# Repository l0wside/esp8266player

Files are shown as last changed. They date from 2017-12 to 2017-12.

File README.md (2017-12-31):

esp8266player - Kindgerechte Steuerung für einen Raumfeld One S
===============================================================

Motivation
----------
Der Player ist inspiriert von der [Toniebox](https://tonies.de/). Wer´s nicht kennt: das Kind hat ein Gerät, darauf stellt es eine Figur (die eine RFID-Kennung enthält), das Gerät lädt sich vom Server die zughörige Audiodatei und spielt los. Kein Gefummel mit CDs, die sowieso immer zerkratzen.

Nachteile an diesem System: man ist auf die Firma angewiesen, ohne Tonies keine Toniebox. Ohne Login geht nichts. Und: alle vorhandenen CDs (und bei uns sind das eine Menge) taugen nur noch als Frisbee oder Briefbeschwerer, eigene Inhalte lassen sich nur schwer wiedergeben.

Umsetzung
---------
Mit der Soft- und Hardware in diesem Projekt lässt sich ein Raumfeld One S per RFID fernsteuern. Dazu wird die sog. URI, die einen Track eindeutig bezeichnet, auf der Mifare-Karte gespeichert. Wird diese Karte dann auf den Player gelegt, sendet diese die URI an den Raumfeld One S, der diese URi dann abspielt. 
Vorteil: alles, was man mit der Raumfeld-App abspielen kann, lässt sich auch auf der Karte speichern. Theoretisch jedenfalls, ich habe es nur mit gerippten CDs auf dem NAS getestet.

Die Bedienung ist maximal simpel: Karte auflegen, ein paar Sekunden warten, Raumfeld dudelt los.

Programmiert werden die Karten ganz einfach: mit der Raumfeld-App einen Track auswählen. Wenn er spielt, auf den Player eine leere Mifare 1k-Karte legen. Der Player erkennt diese und schreibt die URI des aktuellen Tracks darauf. 

Wird die Karte nun wieder aufgelegt, wird der Track als neue URI an den Raumfeld gesendet, und dieser beginnt zu spielen. Wird die Karte weggenommen, wird ein Stop-Befehl an den Raumfeld gesendet.
Alle 20s wird die aktuelle Tracknummer abgefragt und (bei Änderung) auf der Karte gespeichert, so dass, wenn die Karte erneut aufgelegt wird, die CD nicht wieder von vorne losläuft. Was passiert, wenn ein Radiosender oder Spotify eingestellt ist, ist nicht getestet.

Bei uns sind statt RFID-Karten Aufkleber im Einsatz, die auf Holzwürfel geklebt werden. Irgendwann beschrifte ich die noch mit dem Laser.

Sonos und Co
------------
Implementiert ist ganz normales UPnP, das vermutlich mit einer Änderung des initialen Ports (bei Raumfeld 47365) auch mit Sonos läuft. Mangels Sonos habe ich es aber nicht getestet, ich freue mich auf Pull Requests.

Software
--------
Ein erster Umsetzungsversuch mit MicroPython scheiterte am komplett unbenutzbaren Netwerkstack von uPy auf ESP8266. Jetzt basiert die Software auf Arduino. Für RFID nutze ich die Lib von Miguel Balboa, der Zugriff auf den Raumfeld (SOAP über HTTP) ist selbst implementiert.

Hardware
--------
Basis ist ein ESP8266 (ESP13) auf dem im Repository enthaltenen Board. Achtung: der Schaltregler auf dem Board funktioniert zwar prinzipiell, bräuchte aber eine Spule, die größer ist, als der Platz erlaubt. Eine Vorgängerversion hatte mal einen LP3874-3.3 (Linearregler) eingebaut, der funktionierte erheblich besser.
Für Lauter, Leiser, Vor, Zurück sind insgesamt vier Touchfelder vorhanden, die mit Azoteq IQS127D ausgewertet werden. Wer sich das nicht traut, kann auch normale Taster nehmen, muss aber dafür sorgen, dass die Bootkonfiguration weiterhin funktioniert.
Für RFID kommt ein Chinaboard mit RC522 zum Einsatz, wie sie für rund 5 EUR z.B. bei eBay zu bekommen sind.

To Do
-----
* Hardware
  * Nicht funktionierenden Schaltregler sanieren oder durch Linearregler ersetzen
  * Einspeisung über Micro-USB-Buchse statt fest verlöteten Anschluss
  * Die Pinreihenfolge beim Anschluss des RFID-Boards müsste umgedreht werden, dann lässt sich 1:1 verbinden
  * Alternativ: RC522 direkt auf dem Board bestücken und Antenne integrieren.
* Software
  * Ist der Raumfeld im Standby, wird er nicht geweckt. 
  * Gelegentlich funktioniert die Erkennung der RFID-Karten nach einer Weile nicht mehr.
  * Als Status-LED wäre eine WS2812 prima, die dann farblich anzeigen könnte, wie es dem Gerät geht (suche WLAN, suche Raumfeld, Raumfeld gefunden, Karte im Feld, Raumfeld spielt). Das aktuelle Geblinke der blauen LED ist eher nervig.
  * Lauter/Leiser funktioniert nur mittelprächtig (in der App ist das viel besser). Wahrscheinlich wäre es sinnvoll, dafür eine permanent offene HTTP-Verbindung zu halten (also nicht Connection: close, sondern Connection: keep-alive) und mit inkrementellen statt absoluten Lautstärkebefehlen zu arbeiten.

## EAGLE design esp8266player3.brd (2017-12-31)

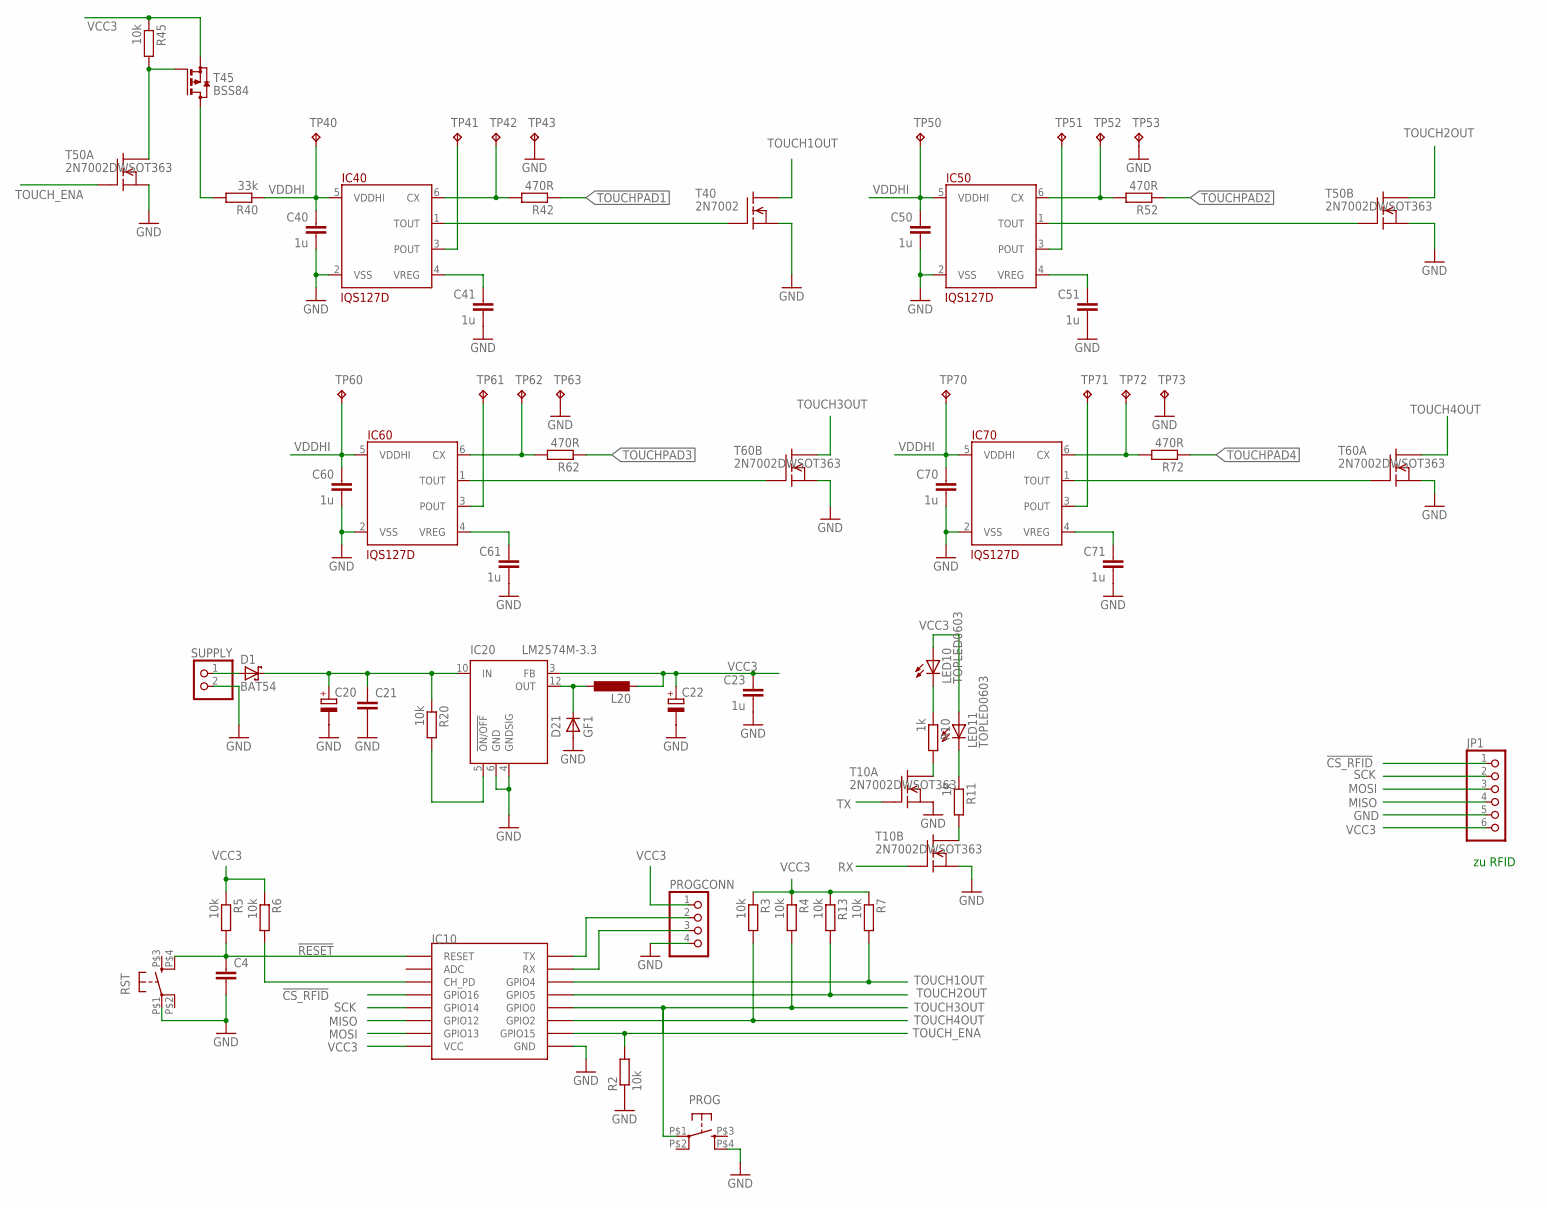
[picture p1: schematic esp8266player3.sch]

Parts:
C4: C-EUC0603; C0603
C20: CPOL-EUC; PANASONIC_C
C21: C-EUC1206; C1206
C22: CPOL-EUF; PANASONIC_F
C23, C40, C41, C50, C51, C60, C61, C70, C71: 1u; C0603
D1: BAT54; SOT23
D21: GF1; SMA-DO214AC
IC10: ESP12SMD; ESP12-SMD
IC20: LM2574M-3.3; SO14W
IC40, IC50, IC60, IC70: IQS127D; SOT23-6
JP1: PINHD-1X6; 1X06
L20: L-EUSRR0603; SRR6603-BOURNS
LED10, LED11: TOPLED0603; LED-0603-OSRAM
PROG: 10-XXTL3305; TL3305
PROGCONN: PINHD-1X4; 1X04
R2, R3, R4, R5, R6, R7, R13, R20, R45: 10k; R0603@1
R10, R11: 1k; R0603@1
R40: 33k; R0603@1
R42, R52, R62, R72: 470R; R0603@1
RST: 10-XXTL3305; TL3305
SUPPLY: PINHD-1X2; 1X02
T10, T50, T60: 2N7002DWSOT363; SOT363
T40: 2N7002; SOT23
T45: BSS84; SOT23
TP40, TP41, TP42, TP43, TP50, TP51, TP52, TP53, TP60, TP61, TP62, TP63, TP70, TP71, TP72, TP73: TPB1,27; B1,27

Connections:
!CS_RFID: IC10.GPIO16, JP1.1
!RESET: C4.1, IC10.RESET, R5.2, RST.P$4 (S1)
GND: C4.2, C20.-, C21.2, C22.-, C23.2, C40.2, C41.2, C50.2, C51.2, C60.2, C61.2, C70.2, C71.2, D21.A, IC10.GND, IC20.4 (GNDSIG), IC20.6 (GND), IC40.2 (VSS), IC50.2 (VSS), IC60.2 (VSS), IC70.2 (VSS), JP1.5, PROG.P$4 (S1), PROGCONN.4, R2.1, RST.P$1, SUPPLY.2, T10.1 (S), T10.4 (S), T40.2 (S), T50.1 (S), T50.4 (S), T60.1 (S), T60.4 (S), TP43.TP, TP53.TP, TP63.TP, TP73.TP
MISO: IC10.GPIO12, JP1.4
MOSI: IC10.GPIO13, JP1.3
unnamed: IC20.5 (!ON/OFF), R20.2
unnamed: D1.1 (A), SUPPLY.1
unnamed: R11.2, T10.6 (D)
unnamed: LED11.K@1 (C), R11.1
unnamed: D21.K (C), IC20.12 (OUT), L20.1
unnamed: LED10.K@1 (C), R10.1
unnamed: R10.2, T10.3 (D)
unnamed: IC10.CH_PD, R6.2
POUT_PROT1: IC60.3 (POUT), TP61.TP
POUT_PROT2: IC40.3 (POUT), TP41.TP
POUT_PROT3: IC70.3 (POUT), TP71.TP
POUT_PROT4: IC50.3 (POUT), TP51.TP
RX: IC10.RXD0 (RX), PROGCONN.3, T10.2 (G)
SCK: IC10.GPIO14, JP1.2
TOUCH1: IC40.1 (TOUT), T40.1 (G)
TOUCH1OUT: IC10.GPIO4, R7.2, T40.3 (D)
TOUCH2: IC50.1 (TOUT), T50.2 (G)
TOUCH2OUT: IC10.GPIO5, R13.2, T50.6 (D)
TOUCH3: IC60.1 (TOUT), T60.2 (G)
TOUCH3OUT: IC10.GPIO0, PROG.P$1, R4.2, T60.6 (D)
TOUCH4: IC70.1 (TOUT), T60.5 (G)
TOUCH4OUT: IC10.GPIO2, R3.2, T60.3 (D)
TOUCHPAD1: R42.1
TOUCHPAD2: R52.1
TOUCHPAD3: R62.1
TOUCHPAD4: R72.1
TOUCH_ENA: IC10.GPIO15, R2.2, T50.5 (G)
TOUCH_ENA2: R45.2, T45.1 (G), T50.3 (D)
TT: IC60.6 (CX), R62.2, TP62.TP
TT1: IC40.6 (CX), R42.2, TP42.TP
TT2: IC70.6 (CX), R72.2, TP72.TP
TT3: IC50.6 (CX), R52.2, TP52.TP
TX: IC10.TXD0 (TX), PROGCONN.2, T10.5 (G)
VCC3: C22.+, C23.1, IC10.VCC, IC20.3 (FB), JP1.6, L20.2, LED10.A@1 (A), LED11.A@1 (A), PROGCONN.1, R3.1, R4.1, R5.1, R6.1, R7.1, R13.1, R45.1, T45.2 (S)
VCC3_TOUCH: R40.2, T45.3 (D)
VDDHI: C40.1, C50.1, C60.1, C70.1, IC40.5 (VDDHI), IC50.5 (VDDHI), IC60.5 (VDDHI), IC70.5 (VDDHI), R40.1, TP40.TP, TP50.TP, TP60.TP, TP70.TP
VIN: C20.+, C21.1, D1.3 (C), IC20.10 (IN), R20.1
VREG1: C61.1, IC60.4 (VREG)
VREG2: C41.1, IC40.4 (VREG)
VREG3: C71.1, IC70.4 (VREG)
VREG4: C51.1, IC50.4 (VREG)

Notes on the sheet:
zu RFID

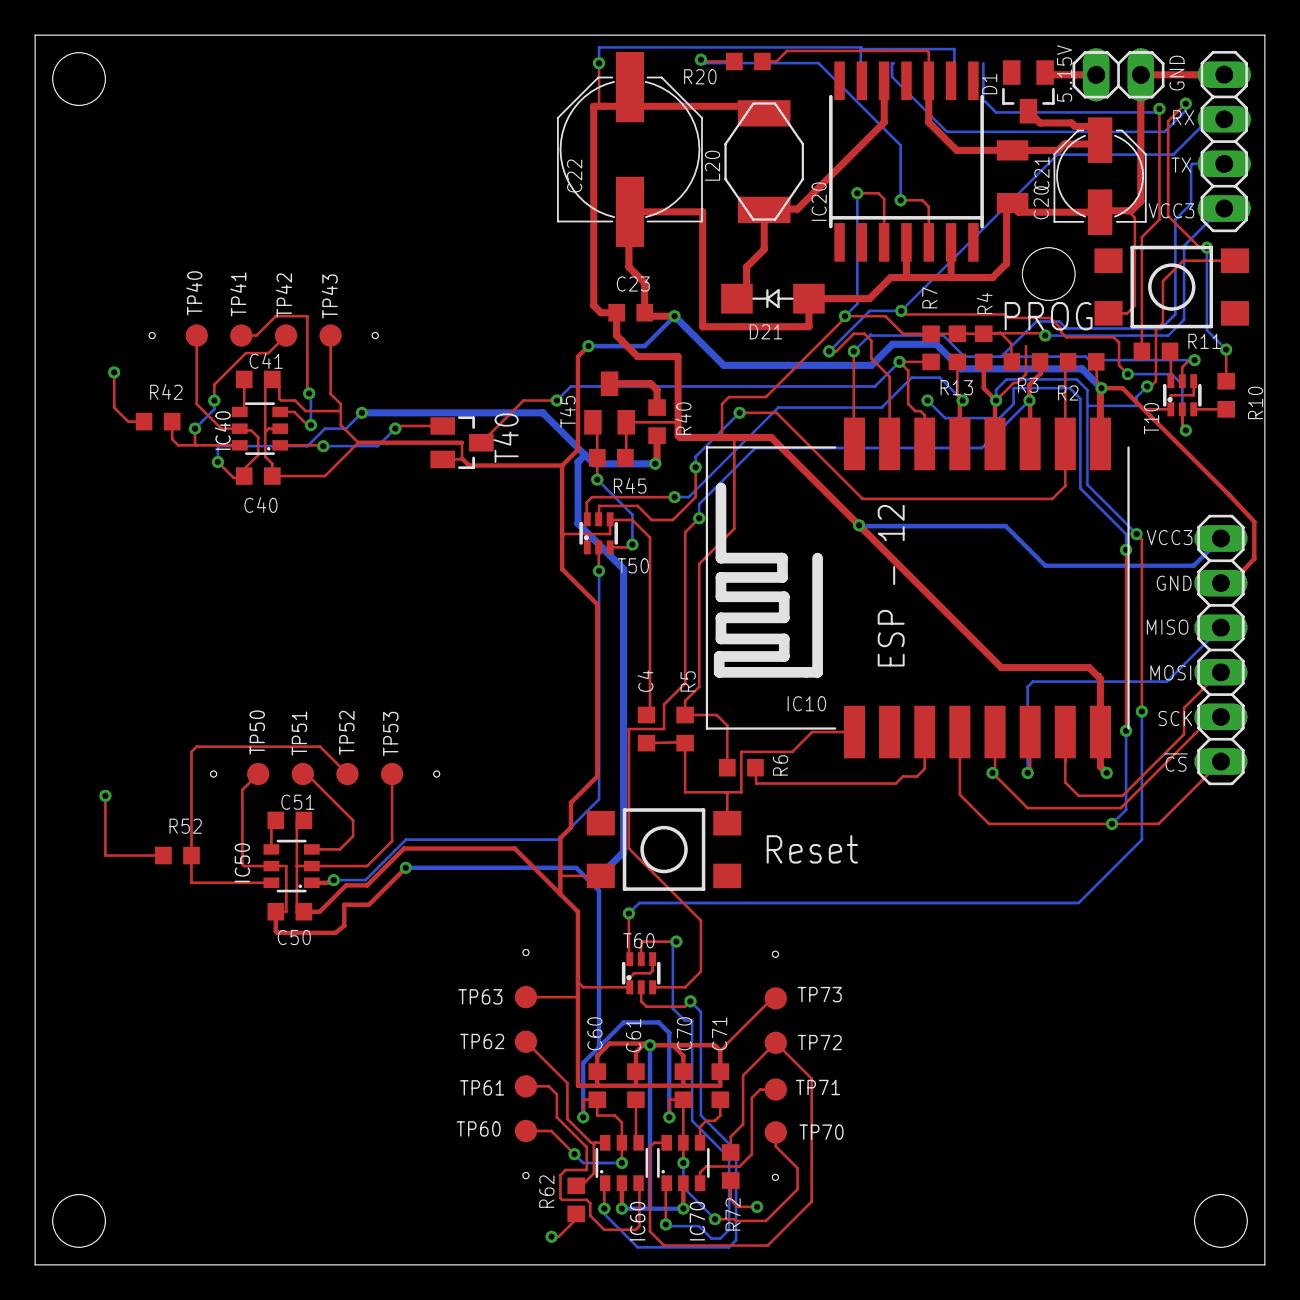
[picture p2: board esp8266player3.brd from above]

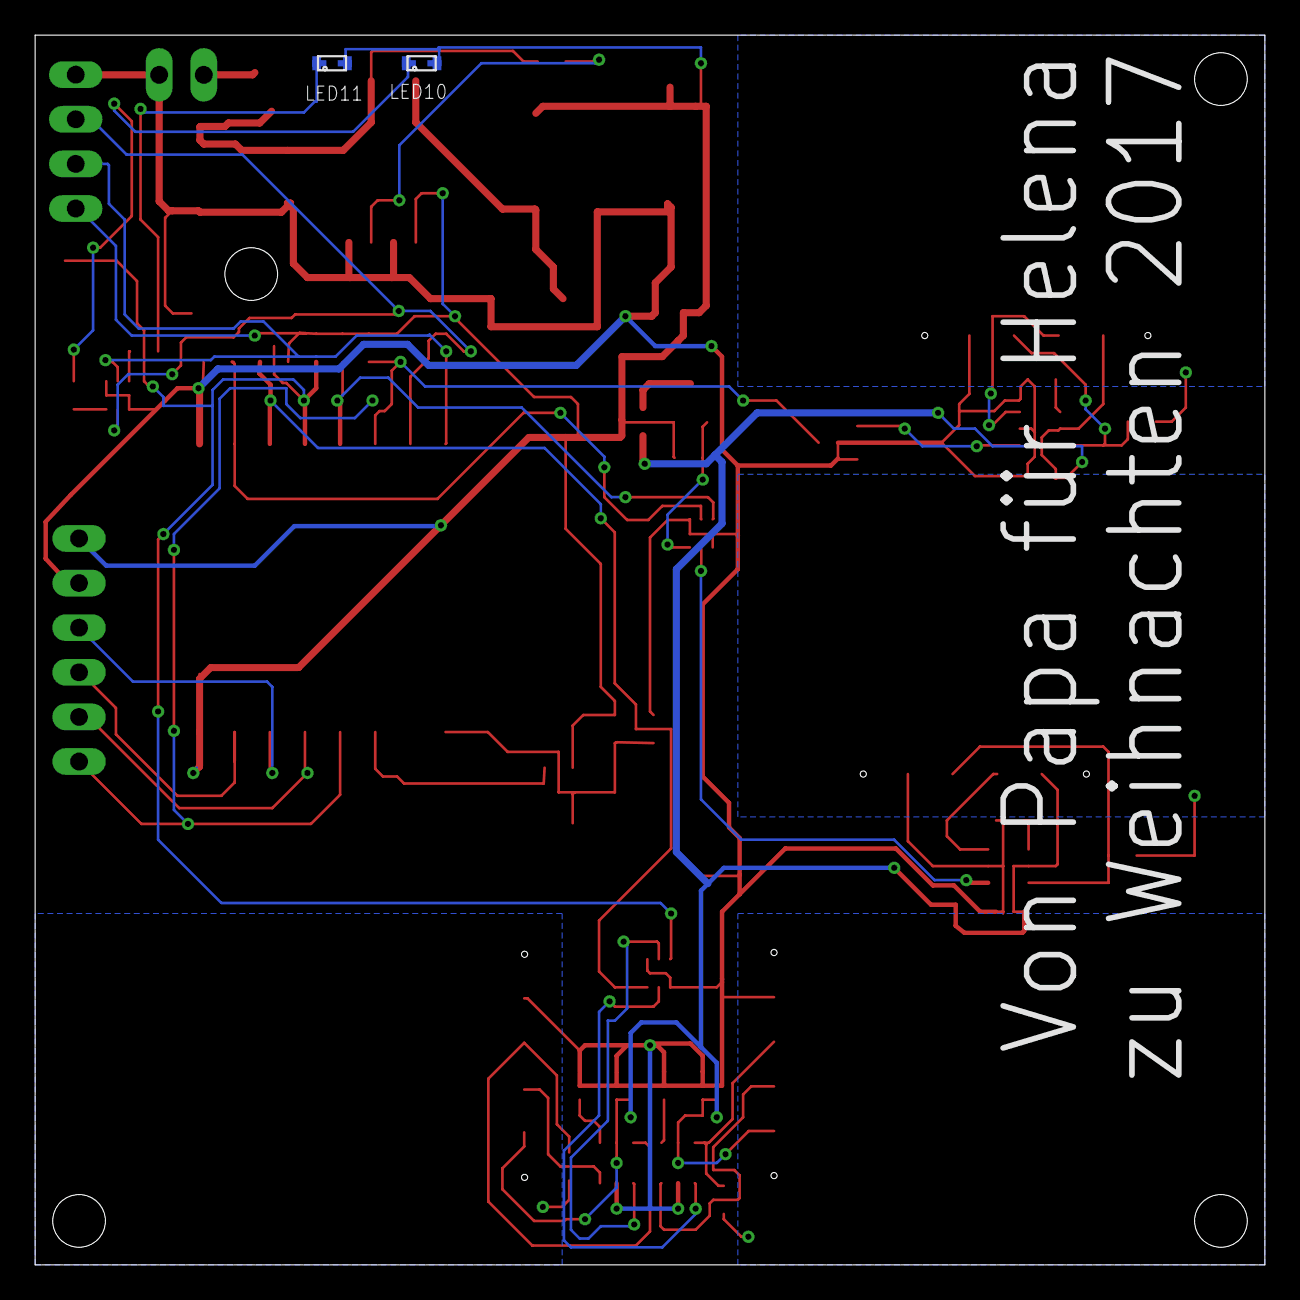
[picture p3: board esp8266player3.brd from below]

Board: 2 copper layers, 70.0 x 70.0 mm, 66 parts (2 on the bottom side), 42 nets.

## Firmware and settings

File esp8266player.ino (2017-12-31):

#include <dummy.h>

#include <SPI.h>
#include <ESP8266WiFi.h>
#include "osapi.h"
extern "C" {
#include "user_interface.h"
}
#include <MFRC522.h>
#include <limits.h>
/* credentials.h must define three constants:
 *  SERVER - the Raumfeld speaker to use
 *  WLAN - the name of the WiFi network
 *  PSK - the WIFi WPA2 key
 */
#include "credentials.h"
#include "raumfeld.h"

extern MFRC522 mfrc522;
MFRC522::MIFARE_Key rf_key;
uint8_t card_present;
void setup_rfid();

#define CARD_DEBOUNCE 10
#define BUFSIZE 1024
char buffer[BUFSIZE];
uint16_t current_track, current_volume, target_volume, last_set_volume;

/* Pin reading */
uint8_t pins[4];
#define VOLUME_UP 0
#define VOLUME_DOWN 2
#define PREV_TRACK 4
#define NEXT_TRACK 5

#define MAX_VOLUME 100 /* Maximum allowed volume level */

#define BLOCKSIZE 256
const uint8_t ID[] = {0x46, 0xc3, 0xbc, 0x72, 0x20, 0x48, 0x65, 0x6c, 0x65, 0x6e, 0x61, 0x20, 0x32, 0x30, 0x31, 0x37};
uint8_t rfid_block[BLOCKSIZE];

/* LED pattern
 * Setup - 0x5555
 * WiFi connected - 0x5050
 * Raumfeld setup - 0x5000
 * Card Removed - 0xF010
 * Card inserted - 0x1111
 * No server found - 0xFFF0
 * Server found - 0x0F0F
 * Loop w/o card interaction - 0xFFFF
 */
uint16_t led_pattern;


/* Cyclic actions:
    - Check availability of server every PING_INTERVAL seconds
    - Check current track number every TRACK_INTERVAL seconds
    - Check card presence every CARD_INTERVAL seconds
    - Increase/decrease volume every VOLUME_INTERVAL milliseconds (if button is pressed)
   Whenever a timer has finished, it sets the corresponding flag,
   which in turn is handled in the main loop.
*/
#define CARD_INTERVAL 2ul
#define PING_INTERVAL 60ul
#define TRACK_INTERVAL 20ul
#define VOLUME_INTERVAL 500ul
os_timer_t timer_ping, timer_card, timer_track, timer_volume, timer_led;

bool flag_track = false;
void cbTimerTrack(void *arg) {
  flag_track = true;
}

bool flag_ping = false;
void cbTimerPing(void *arg) {
  flag_ping = true;
}

bool flag_card = false;
void cbTimerCard(void *arg) {
  flag_card = true;
}

uint32_t volume_press_time = ULONG_MAX;
bool flag_volume = false;
void cbTimerVolume(void *arg) {
  flag_volume = true;
}
enum {
  volume_none,
  volume_up,
  volume_down,
  volume_up_finish,
  volume_down_finish
} volume_dir;

enum {
  pn_none,
  pn_prev,
  pn_next
} flag_prevnext;

// the setup function runs once when you press reset or power the board
void setup() {
  // init LED (pin 2). The bits in led_pattern are written cyclically to the LED.
  pinMode(2, OUTPUT);
  
  Serial.begin(38400);

  WiFi.begin(WLAN, PSK);

  while (WiFi.status() != WL_CONNECTED) {
    for (uint8_t n=0; n < 5; n++) {
      digitalWrite(2,HIGH);
      delay(50);
      digitalWrite(2,LOW);
      delay(50);
    }
    
    Serial.print(".");
  }

  setup_raumfeld();
  
  setup_rfid();

  card_present = false;
  for (uint8_t n = 0; n < 6; n++) {
    rf_key.keyByte[n] = 0xFF;
  }

  /* Enable Touch */
  memset(pins, 0, 4);
  pinMode(15, OUTPUT); /* Touch Enable pin */
  digitalWrite(15, LOW); /* Touch off */

  /* Setup timer structure */
  flag_prevnext = pn_none;
  volume_dir = volume_none;
  flag_track = flag_ping = flag_card = flag_volume = false;

  Serial.println("Arming timers");
  os_timer_setfn(&timer_card, cbTimerCard, NULL);
  os_timer_arm(&timer_card, 1000 * CARD_INTERVAL, true);
  os_timer_setfn(&timer_ping, cbTimerPing, NULL);
  os_timer_arm(&timer_ping, 1000 * PING_INTERVAL, true);
  os_timer_setfn(&timer_track, cbTimerTrack, NULL);
  os_timer_setfn(&timer_volume, cbTimerVolume, NULL);

}

void cbTimerLED(void*) {
  return;
  if (led_pattern & 0x01) {
    digitalWrite(2,HIGH);
    led_pattern >>= 1;
    led_pattern |= 0x8000;
  } else {
    digitalWrite(2,LOW);
    led_pattern >>= 1;
    led_pattern &= 0x7FFF;
  }
}

void enablePinsAndTimers() {
  digitalWrite(15, HIGH); /* Touch on */

  pinMode(VOLUME_UP, INPUT);
  pinMode(VOLUME_DOWN, INPUT);
  pinMode(PREV_TRACK, INPUT);
  pinMode(5, INPUT);
  attachInterrupt(digitalPinToInterrupt(VOLUME_UP), cbPin, CHANGE);
  attachInterrupt(digitalPinToInterrupt(VOLUME_DOWN), cbPin, CHANGE);
  attachInterrupt(digitalPinToInterrupt(PREV_TRACK), cbPin, CHANGE);
  attachInterrupt(digitalPinToInterrupt(NEXT_TRACK), cbPin, CHANGE);

  os_timer_arm(&timer_track, TRACK_INTERVAL * 1000, true);
}

void disablePinsAndTimers() {
  detachInterrupt(digitalPinToInterrupt(VOLUME_UP));
  detachInterrupt(digitalPinToInterrupt(VOLUME_DOWN));
  detachInterrupt(digitalPinToInterrupt(PREV_TRACK));
  detachInterrupt(digitalPinToInterrupt(NEXT_TRACK));
  digitalWrite(15, LOW); /* Touch off */
  pinMode(2, OUTPUT); /* LED */

  os_timer_disarm(&timer_track);
}

/* Converts a keypress time interval (in ms) to a new target volume.
    < 500 ms: 1 step
    0.5...3s: 4 steps/s
    > 3s: 10 steps/s
*/
uint16_t updateVolume(uint32_t interval) {
  uint16_t volumedelta = 3;
  uint32_t n;

  if (interval <= 0) {
    return current_volume;
  }

  for (n = 500; n < 3000; n += 250) {
    if (interval > n) {
      volumedelta++;
    } else {
      break;
    }
  }
  for (n = 3000; n < 20000; n += 100) {
    if (interval > n) {
      volumedelta++;
    } else {
      break;
    }
  }
  Serial.println("updateVolume(): timedelta " + String(interval) + " = delta " + String(volumedelta) + ", current volume " + String(current_volume) + ", dir " + String(volume_dir));

  switch (volume_dir) {
    case volume_down:
    case volume_down_finish:
      if (volumedelta < current_volume) {
        Serial.println("updateVolume() (dn): returning " + String(current_volume) + "-" + String(volumedelta));
        return current_volume - volumedelta;
      } else {
        return 0;
      }
      break;
    case volume_up:
    case volume_up_finish:
      if (volumedelta + current_volume < MAX_VOLUME) {
        Serial.println("updateVolume() (up): returning " + String(volumedelta) + "+" + String(current_volume));
        return current_volume + volumedelta;
      } else {
        Serial.println("updateVolume(): returning MAXVOLUME");
        return MAX_VOLUME;
      }
      break;
    default:
      return current_volume;
  }
}

void cardRemoved() {
  card_present = false;
  Serial.println("Card removed");

  stop();
  disablePinsAndTimers();
  digitalWrite(2,LOW);
}

/****************************************************************************
   Unknown card
   Find out if the speaker is playing. If so, fetch the URI and write it to the card.
 ***************************************************************************/
void unknownCard() {
  Serial.println("Handling unknown card");
  digitalWrite(2,HIGH);
  if (!playing()) {
    Serial.println("Not playing, return");
    mfrc522.PICC_HaltA();
    mfrc522.PCD_StopCrypto1();
    delay(100);
    mfrc522.PCD_Init();
    return;
  }

  /* Find out URI... */
  String uri = geturi();

  if (uri.length() < 10) {
    Serial.println("No proper URI found");
    mfrc522.PICC_HaltA();
    mfrc522.PCD_StopCrypto1();
    delay(100);
    mfrc522.PCD_Init();
    return;
  }

  /* ...and write it to card */
  MFRC522::StatusCode status;
  int idx = 0;
  uint8_t block_buf[18];
  uint8_t block_size = sizeof(block_buf);
  uint8_t blockno = 5;
  bool last_block = false;
  for (blockno = 8; blockno < 64; blockno++) {
    if (blockno % 4 == 3) {
      continue;
    }

    memset(block_buf, 0, 17);
    if (uri.length() > idx + 16) {
      uri.substring(idx, idx + 16).toCharArray((char*)block_buf, 17);
      Serial.print("Block " + String(blockno) + ": " + uri.substring(idx, idx + 15) + "#");
    } else {
      uri.substring(idx).toCharArray((char*)block_buf, 17);
      Serial.println("Last block " + String(blockno) + ": " + uri.substring(idx));
      last_block = true;
    }
    idx += 16;

    if (blockno % 4 == 0) {
      status = (MFRC522::StatusCode) mfrc522.PCD_Authenticate(MFRC522::PICC_CMD_MF_AUTH_KEY_A, blockno + 3, &rf_key, &(mfrc522.uid));
      if (status != MFRC522::STATUS_OK) {
        Serial.println("Auth failed during write, block " + String(blockno) + " status " + String(status));
        mfrc522.PICC_HaltA();
        mfrc522.PCD_StopCrypto1();
        delay(100);
        mfrc522.PCD_Init();
        return;
      }
    }

    status = (MFRC522::StatusCode) mfrc522.MIFARE_Write(blockno, block_buf, 16);
    if (status != MFRC522::STATUS_OK) {
      Serial.print(F("MIFARE_Write() failed: "));
      Serial.println(mfrc522.GetStatusCodeName(status));
      mfrc522.PICC_HaltA();
      mfrc522.PCD_StopCrypto1();
      delay(100);
      mfrc522.PCD_Init();
      return;
    }
    if (last_block) {
      break;
    }
  }
  /* Write a block of zeroes for termination after last real block */
  blockno++;
  if (blockno % 4 == 0) {
    status = (MFRC522::StatusCode) mfrc522.PCD_Authenticate(MFRC522::PICC_CMD_MF_AUTH_KEY_A, blockno + 3, &rf_key, &(mfrc522.uid));
    if (status != MFRC522::STATUS_OK) {
      Serial.println("Auth failed during write, block " + String(blockno) + " status " + String(status));
      mfrc522.PICC_HaltA();
      mfrc522.PCD_StopCrypto1();
      delay(100);
      mfrc522.PCD_Init();
      return;
    }
  }
  memset(block_buf, 0, 16);
  status = (MFRC522::StatusCode) mfrc522.MIFARE_Write(blockno, block_buf, 16);
  if (status != MFRC522::STATUS_OK) {
    Serial.print(F("MIFARE_Write() failed: "));
    Serial.println(mfrc522.GetStatusCodeName(status));
    mfrc522.PICC_HaltA();
    mfrc522.PCD_StopCrypto1();
    delay(100);
    mfrc522.PCD_Init();
    return;
  }

  /* Write track #1 to card (first two bytes of block 5) */
  status = (MFRC522::StatusCode) mfrc522.PCD_Authenticate(MFRC522::PICC_CMD_MF_AUTH_KEY_A, 7, &rf_key, &(mfrc522.uid));
  if (status != MFRC522::STATUS_OK) {
    Serial.println("Auth failed during write, block 7, status " + String(status));
    mfrc522.PICC_HaltA();
    mfrc522.PCD_StopCrypto1();
    delay(100);
    mfrc522.PCD_Init();
    return;
  }

  blockno = 5;
  memset(block_buf, 0, 16);
  block_buf[0] = 0;
  block_buf[1] = 1;
  status = (MFRC522::StatusCode) mfrc522.MIFARE_Write(blockno, (uint8_t*)block_buf, 16);
  if (status != MFRC522::STATUS_OK) {
    Serial.print(F("MIFARE_Write() failed at block 5: "));
    Serial.println(mfrc522.GetStatusCodeName(status));
    mfrc522.PICC_HaltA();
    mfrc522.PCD_StopCrypto1();
    delay(100);
    mfrc522.PCD_Init();
    return;
  }

  /* Looks like we were successful, so write ID to block 4.
    Same sector as before, no re-authentication necessary
  */
  blockno = 4;
  status = (MFRC522::StatusCode) mfrc522.MIFARE_Write(blockno, (uint8_t*)ID, 16);
  if (status != MFRC522::STATUS_OK) {
    Serial.print(F("MIFARE_Write() failed at block 4: "));
    Serial.println(mfrc522.GetStatusCodeName(status));
    mfrc522.PICC_HaltA();
    mfrc522.PCD_StopCrypto1();
    delay(100);
    mfrc522.PCD_Init();
    return;
  }
  for (uint8_t n=0; n < 10; n++) {
    digitalWrite(2,LOW);
    delay(200);
    digitalWrite(2,HIGH);
    delay(200);
  }
}

/****************************************************************************
 Card with matching ID
 Read the URI and send it to the speaker
***************************************************************************/
void knownCard() {
  String uri;
  uint8_t blockno;
  uint8_t block_buf[18];
  uint8_t block_size = sizeof(block_buf);
  MFRC522::StatusCode status;
  digitalWrite(2,HIGH);
  
  for (blockno = 8; blockno < 64; blockno++) {
    if (blockno % 4 == 3) {
      continue;
    }
    if (blockno % 4 == 0) {
      status = (MFRC522::StatusCode) mfrc522.PCD_Authenticate(MFRC522::PICC_CMD_MF_AUTH_KEY_A, blockno + 3, &rf_key, &(mfrc522.uid));
      if (status != MFRC522::STATUS_OK) {
        Serial.println("Auth failed during write, block " + String(blockno) + " status " + String(status));
        mfrc522.PICC_HaltA();
        mfrc522.PCD_StopCrypto1();
        delay(100);
        mfrc522.PCD_Init();
        return;
      }
    }
    block_size = sizeof(block_buf);
    memset(block_buf, 0, sizeof(block_buf));
    status = (MFRC522::StatusCode)mfrc522.MIFARE_Read(blockno, block_buf, &block_size);
    if (status != MFRC522::STATUS_OK) {//|| (size < BLOCKSIZE)) {
      Serial.println("Read failed, status " + String(status) + " size " + String(block_size));
      mfrc522.PICC_HaltA();
      mfrc522.PCD_StopCrypto1();
      delay(100);
      mfrc522.PCD_Init();
      return;
    }

    block_buf[16] = 0;
    String block = String((char*)block_buf);
    uri = uri + block;
    if (block.length() < 16) {
      break;
    }
  }

  /* Read track number */
  status = (MFRC522::StatusCode) mfrc522.PCD_Authenticate(MFRC522::PICC_CMD_MF_AUTH_KEY_A, 7, &rf_key, &(mfrc522.uid));
  if (status != MFRC522::STATUS_OK) {
    Serial.println("Auth failed during read, block 7, status " + String(status));
    mfrc522.PICC_HaltA();
    mfrc522.PCD_StopCrypto1();
    delay(100);
    mfrc522.PCD_Init();
    return;
  }
  blockno = 5;
  block_size = sizeof(block_buf);
  memset(block_buf, 0, sizeof(block_buf));
  status = (MFRC522::StatusCode)mfrc522.MIFARE_Read(blockno, block_buf, &block_size);
  if (status != MFRC522::STATUS_OK) {//|| (size < BLOCKSIZE)) {
    Serial.println("Read failed, status " + String(status) + " size " + String(block_size));
    mfrc522.PICC_HaltA();
    mfrc522.PCD_StopCrypto1();
    delay(100);
    mfrc522.PCD_Init();
    return;
  }
  current_track = (int16_t)((((uint16_t)(block_buf[0])) << 8) + block_buf[1]);
  Serial.println("Track block data " + String(block_buf[0]) + " " + block_buf[1]);
  Serial.println("Track #" + String(current_track));
  if ((current_track <= 0) || (current_track >= 0x7FFE)) {
    current_track = 1;
  }

  /* Send URI and track to speaker */
  if (uri.length() < BUFSIZE) {
    current_volume = -1;
    int16_t read_volume = -1;
    uri.toCharArray(buffer, uri.length() + 1);
    Serial.println("seturi()");
    delay(100);
    seturi(buffer);
    Serial.println("play(), track is " + String(current_track));
    delay(100);
    settrack(current_track);
    delay(100);
    play();
    delay(100);
    read_volume = getVolume();
    if (read_volume >= 0) {
      current_volume = read_volume;
    }
  }
  enablePinsAndTimers();
}

// the loop function runs over and over again forever
void loop() {
  if (!server_found) {
    digitalWrite(2,LOW);
    clearServers();
    findServers();
    if (n_servers > 0) {
      led_pattern = 0x0F0F;
      server_found = true;
    }
    default_server = 0;
    Serial.println("Finding servers, result " + String (n_servers) + ", default " + String(default_server));
    return;
  }
  digitalWrite(2,HIGH);
  delay(100);
  digitalWrite(2,LOW);
  delay(100);
  if (!flag_track && !flag_ping && !flag_card && /*!flag_volume */ (volume_dir == volume_none) && (flag_prevnext == pn_none)) {
    return;
  }

  /* Check server for availability */
  if (flag_ping) {
    flag_ping = false;
    if (!ping(0)) {
      server_found = false;
    }
  }

  /* Send prev/next commands */
  if (flag_prevnext == pn_prev) {
    flag_prevnext = pn_none;
    prev();
  }
  if (flag_prevnext == pn_next) {
    flag_prevnext = pn_none;
    next();
  }

  if ((volume_dir != volume_none)) { // flag_volume) {
    flag_volume = false;
    if (!card_present) {
      volume_dir = volume_none;
      return;
    }
    Serial.println("flag_volume handler, dir is " + String(volume_dir) + ", CV now " + String(current_volume) + " TV " + String(target_volume));
    flag_volume = false;
    Serial.println("old target volume " + String(target_volume));
    target_volume = updateVolume(millis() - volume_press_time);
    Serial.println("Setting volume to new target volume " + String(target_volume));
    setVolume(target_volume);
    if ((volume_dir == volume_down_finish) || (volume_dir == volume_up_finish)) {
      current_volume = target_volume;
      volume_dir = volume_none;
      Serial.println("CV now " + String(current_volume) + " TV " + String(target_volume));
    }
  }

  /* Read current track cyclically and write it to the card (if it has changed) */
  if (flag_track) {
    flag_track = false;
    if (!card_present) {
      return;
    }

    int16_t read_track = -1;
    if (!playing()) {
      read_track = 1;
    }
    if (read_track == 0) {
      read_track = 1;
    }
    if ((read_track < 0) || (read_track == current_track)) {
      return;
    }
    current_track = read_track;
    Serial.println("Updating track on card to #" + String(current_track));
    /* Write track # to card (first two bytes of block 5) */
    if (!mfrc522.PICC_ReadCardSerial()) {
      Serial.println("Cannot read card serial number");
      mfrc522.PICC_HaltA();
      mfrc522.PCD_StopCrypto1();
      delay(100);
      mfrc522.PCD_Init();
      return;
    }
    
    MFRC522::StatusCode status;
    status = (MFRC522::StatusCode) mfrc522.PCD_Authenticate(MFRC522::PICC_CMD_MF_AUTH_KEY_A, 7, &rf_key, &(mfrc522.uid));
    if (status != MFRC522::STATUS_OK) {
      Serial.println("Auth failed during write, block 7, status " + String(status));
      mfrc522.PICC_HaltA();
      mfrc522.PCD_StopCrypto1();
      delay(100);
      mfrc522.PCD_Init();
      return;
    }

    uint8_t block_buf[18];
    uint8_t block_size = sizeof(block_buf);
    uint8_t blockno = 5;
    memset(block_buf, 0, 16);
    block_buf[0] = (uint8_t)((((uint16_t)current_track) >> 8) & 0xFF);
    block_buf[1] = (uint8_t)(((uint16_t)current_track) & 0xFF);
    status = (MFRC522::StatusCode) mfrc522.MIFARE_Write(blockno, (uint8_t*)block_buf, 16);
    if (status != MFRC522::STATUS_OK) {
      Serial.print(F("MIFARE_Write() failed at block 5: "));
      Serial.println(mfrc522.GetStatusCodeName(status));
    }
    mfrc522.PICC_HaltA();
    mfrc522.PCD_StopCrypto1();
    delay(100);
    mfrc522.PCD_Init();
    return;
  }

  /****** Card handling *********/
  if (flag_card) {
    flag_card = false;

    MFRC522::StatusCode status;
    uint8_t block_buf[18];
    uint8_t block_size = sizeof(block_buf);
    uint8_t blockno = 4;

    String uri = String();

    bool card_detected;
    card_detected = mfrc522.PICC_IsNewCardPresent();
    if (card_present && !card_detected) {
      card_detected = mfrc522.PICC_IsNewCardPresent();
    }

    if (card_detected == card_present) {
      Serial.print(String(card_present));
      return;
    }
    Serial.println("detected " + String(card_detected) + "present " + String(card_present));
    if (!card_detected) {
      for (uint8_t n = 0; n < CARD_DEBOUNCE; n++) {
        delay(100);
        Serial.print("?");
        if (mfrc522.PICC_IsNewCardPresent()) {
          Serial.println("+");
          card_present = true;
          return;
        }
      }
      Serial.println("-");
      /* Card removed */
      cardRemoved();
      return;
    }
    Serial.println("Card inserted");

    if (!mfrc522.PICC_ReadCardSerial()) {
      Serial.println("Cannot read card serial number");
      return;
    }

    Serial.print(F("PICC type: "));
    MFRC522::PICC_Type piccType = mfrc522.PICC_GetType(mfrc522.uid.sak);
    Serial.println(mfrc522.PICC_GetTypeName(piccType));
    // Check for compatibility
    if (piccType != MFRC522::PICC_TYPE_MIFARE_MINI
        &&  piccType != MFRC522::PICC_TYPE_MIFARE_1K
        &&  piccType != MFRC522::PICC_TYPE_MIFARE_4K) {
      Serial.println(F("Not a MIFARE Classic card."));
      return;
    }


    /* ID is in sector 1 (block 4).
        Base data (URI of first track) starts in sector 2 (block 8)
        and is written continuously in the first three blocks of each sector (i.e. 8,9,10,12,13,14,...)
        The last track number is written in the first two bytes of block 5.
    */
    status = (MFRC522::StatusCode) mfrc522.PCD_Authenticate(MFRC522::PICC_CMD_MF_AUTH_KEY_A, 7, &rf_key, &(mfrc522.uid));
    if (status != MFRC522::STATUS_OK) {
      Serial.println("Auth failed " + String(status));
      mfrc522.PICC_HaltA();
      mfrc522.PCD_StopCrypto1();
      delay(100);
      mfrc522.PCD_Init();
      return;
    }

    block_size = sizeof(block_buf);
    blockno = 4;
    status = (MFRC522::StatusCode) mfrc522.MIFARE_Read(blockno, block_buf, &block_size);
    if (status != MFRC522::STATUS_OK) {//|| (size < BLOCKSIZE)) {
      Serial.println("Read failed, status " + String(status) + " size " + String(block_size));
      mfrc522.PICC_HaltA();
      mfrc522.PCD_StopCrypto1();
      delay(100);
      mfrc522.PCD_Init();
      return;
    }

    if (!memcmp(ID, block_buf, 16)) {
      Serial.println("Known card");
      knownCard();
    } else {
      Serial.println("Unknown card");
      unknownCard();
    }

    mfrc522.PICC_HaltA();
    mfrc522.PCD_StopCrypto1();
    mfrc522.PCD_Init();
    card_present = true;
  } /* End of card insert/remove handling */
}
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

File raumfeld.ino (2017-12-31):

#include "credentials.h"
#include "raumfeld.h"

#define BUFSIZE 16384
#define TAGSIZE 30
#define RENDERCONTROL "urn:schemas-upnp-org:service:RenderingControl:1"
#define TRANSPORTCONTROL "urn:schemas-upnp-org:service:AVTransport:1"
#define ACTION_CHANGEVOLUME "ChangeVolume"
#define ACTION_GETVOLUME "GetVolume"
#define ACTION_PLAY "Play"
#define ACTION_SEEK "Seek"
#define ACTION_NEXT "Next"
#define ACTION_GETMEDIAINFO "GetMediaInfo"
#define ACTION_GETTRANSPORTINFO "GetTransportInfo"


server_t servers[MAXSERVERS];
uint8_t n_servers;
uint8_t default_server;
bool server_found;

IPAddress server_ip;


char stringbuf[4*STRINGSIZE];
char http_buf[BUFSIZE];
char _server[STRINGSIZE];
char _path[STRINGSIZE];
char xml_desc[STRINGSIZE];
char scdp_rendering[STRINGSIZE], scdp_transport[STRINGSIZE];

void setup_raumfeld() {
  server_found = false;
  n_servers = 0;

  WiFi.hostByName(SERVER,server_ip);
}

String http_post(const char *server, uint16_t port, const char *path, const char *postdata, const char *extraheader, const char *content_type, uint8_t max_redirects, uint16_t *http_status) {
  uint16_t _port;
  String body;

  bool redirect = true;
  uint8_t n_redirects = 0;

  if (extraheader == 0) {
    extraheader = "";
  }
  if (postdata == NULL) {
    postdata = "";
  }
  if (content_type == 0) {
    content_type = "application/x-www-form-urlencoded";
  }
  if (http_status != 0) {
    *http_status = 0;
  }

  strncpy(_server, server, STRINGSIZE);
  strncpy(_path, path, STRINGSIZE);
  _port = port;

  while ((n_redirects < max_redirects) && redirect) {
    snprintf(http_buf, BUFSIZE, "POST %s HTTP/1.1\r\n"
             "Host: %s\r\n"
             "User-Agent: u_http\r\n"
             "Accept: */*\r\n"
             "%s"
             "Content-type: %s\r\n"
             "Content-length: %i\r\n"
             "Connection: close\r\n\r\n"
             "%s\r\n",
             _path,
             _server,
             extraheader,
             content_type,
             strlen(postdata),
             postdata);

    IPAddress server_address;
    delay(0);
    WiFi.hostByName(_server, server_address);
    //    Serial.print(String("Connect to ") + _server + " " + String(_port)+ " ");
    //    Serial.println(server_address);
    delay(0);

    WiFiClient client;
    int res = client.connect(server_address, _port);
    delay(0);
    if (!res) {
      return String();
    }

    //        Serial.print(buf);

    Serial.print("H");
    client.print(http_buf);
    delay(0);
    Serial.print("h");

    unsigned long timeout = millis();
    while (client.available() == 0) {
      delay(0);
      if (millis() - timeout > 5000) {
        Serial.println(">>> Client Timeout !");
        client.stop();
        return String();
      }
    }
    Serial.print("+" + String(client.connected()) + "a:" + String(client.available()) + "~~ ");
    _path[0] = 0;
    delay(0);

    // Read all the lines of the reply from server and print them to Serial
    timeout = millis();
    uint16_t lno = 0;
    bool header = true;
    char *bufptr;
    uint16_t total_len = 0;
    while (client.connected()) {
      delay(0);
      if (millis() - timeout > 5000) {
        Serial.println("POST: Client Timeout 1");
        client.stop();
        return String();
      }

      String line = client.readStringUntil('\n');
      delay(0);
//      Serial.print("["+String(line.length()) +"]");
      if (header) {
//        Serial.println("@" + line);
        line.toCharArray(http_buf, line.length());
        http_buf[line.length()] = 0;
        //        Serial.print("*");
        //        Serial.print(buf);
        //        Serial.println("*");

        if (lno == 0) {
          if ((strlen(http_buf) < 13) || (strncmp("HTTP/1.1 ", http_buf, 9))) {
            /* Not HTTP or no status code */
            Serial.println("Unexpected first header line " + line);
            return String();
          }
          char status[4];
          strncpy(status, http_buf + 9, 3);
          status[3] = 0;
          if (status[0] == '3') {
            redirect = true;
          } else {
            redirect = false;
          }
          Serial.print("HTTP Status " + String(status));
          if (http_status) {
            *http_status = atoi(status);
          }
        }
        if (redirect && (lno > 0) && (!strncmp("LOCATION: ", http_buf, 10) || !strncmp("Location: ", http_buf, 10))) {
          char *addr = http_buf + 10;
          Serial.println("HTTP Redirect to " + String(addr));
          strncpy(_path, addr, STRINGSIZE);
          n_redirects++;
          continue;
        }
/*        if (line.startsWith("Content-Length: 0")) {
          client.stop();
          return String("");
        } */
        if (line.length() < 2) {
          if (redirect && (strlen(_path) == 0)) {
            /* Redirect, end of header, no location */
            client.stop();
            return String();    
          }
          header = false;
          body = "";
        }
      } else { /* Body */
        delay(0);
        if (line.length() > 0) {
          body = body + line;
        }
      }

      lno++;
    }

    client.stop();
  }

  Serial.println("$$" + String(body.length()));
  return body;
}

bool http_get(const char *server, uint16_t port, const char *path, char *outbuf) {

  snprintf(http_buf, BUFSIZE, "GET %s HTTP/1.1\r\n"
           "Host: %s\r\n"
           "User-Agent: u_http\r\n"
           "Accept: */*\r\n"
           "Connection: close\r\n\r\n",
           path,
           server);

  Serial.println("GET: " + String(http_buf));
           
  IPAddress server_address;
  delay(0);
  WiFi.hostByName(server, server_address);
//Serial.print(String("Connect to ") + server + " " + String(port)+ " ");
//Serial.println(server_address);
  delay(0);

  WiFiClient client;
  int res = client.connect(server_address, port);
  delay(0);
  if (!res) {
    Serial.println("GET: Cannot connect to " + String(server) + ", port " + String(port));
    return false;
  }

  //        Serial.print(buf);

//  Serial.print(":H");
  client.print(http_buf);
  delay(0);
//  Serial.print(":h");

  unsigned long timeout = millis();
  while (client.available() == 0) {
    delay(0);
    if (millis() - timeout > 5000) {
      Serial.println(">>> Client Timeout 1");
      client.stop();
      return false;
    }
  }
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
